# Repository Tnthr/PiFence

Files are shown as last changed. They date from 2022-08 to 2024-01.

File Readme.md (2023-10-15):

# About PiFence

An arduino script and a shell script for use as a fence agent on a custom built power supply for a five node raspberry pi cluster.

The shell script is a fence agent designed to be used with pacemaker in a HA environment. 
The Arduino program is for an Arduino with ethernet shield connected to five seperate relays that operate five USB power supplies. This setup allows the Arduino to function as a STONITH device for a five node Raspberry Pi cluster.

The whole project is pretty rough but it works well enough for "production" use. Plenty of room for improvement though.
Recently added the first revision of a custom PCB. All of the files are from KiCAD. I do not recommend using this PCB design as is because it is extremely simple and only uses various breakout boards. The next version will be a real PCB that includes all of the discrete components. 

The project is designed to fit into a Raspberry Pi cluster case to be self-contained. Link to the case used is below.
https://www.printables.com/en/model/182055-raspberry-pi-4-cluster-case

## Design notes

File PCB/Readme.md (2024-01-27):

# About PiFence PCB

The fence device is custom-made hardware that is run by the firmware in this repository. This PCB folder is the hardware.

The core of the hardware is an Arduino that controls five relays powering five USB ports. These ports provide power to each of five Raspberry Pi devices and the Arduino provides fencing capability. The Arduino has an ethernet port interface to provide external control.

The board has a power port for 18V input to supply the arduino and the five powered USB ports. 

Future plans include adding a USB C power input, two four-pin fan outputs, a 12V power output for the router, and integrating the ethernet port as well as converting the power outputs to USB C.

# Theory

The USB-C PD spec can deliver 20 volts and 5 amps which will provide up to 100 watts. This is plenty to power all of the board components. An alternate option is 15 volts at 3 amps. This will be just enough to power everything so long as there is not a high load on anything. Futher testing is probably required to ensure at least the initial bootup of all servers can be handled at the lower power level before providing support for it.

At the 20 volt input level power cannot be applied directly to the Arduino so a power step down will be required. A 12V step down will allow power to be applied to the arduino and to the router. A 5V step down with enough current output will be needed for the RPi power outputs and the fans.

Control of the fans should be provided by the Arduino. A temperature sensor will be added to the computer area of the case to provide input for controlling the speed of the fans.

# Component list

| Item | Model | Quantity |
| --- | --- | --- |
| MCU | Arduino Nano Every | 1 |
| 12V Step down | | 1 |
| 5V Step down  | | ? |
| Ethernet jack | | 1 |
| Relay | PR13-5V-450-1C | 5 |
| Temp sensor | | 1 |
| USB C Port | | 6 |

# Power requirements for all of the components

| Item | Qty | Volt | Draw | Total  |
| --- | --- | ---- | ---- | --- |
| RPi4 | 5 | 5V | 1.3A | 32.5W  |
| Fan | 2 | 5V | 0.2A | 2W |
| Router  | 1 | 12V  | 1A | 12W |
| Arduino | 1 | 5V | 25mA | 0.125W |

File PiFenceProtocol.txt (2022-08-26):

# PiFence protocol standard
# Version 0.1
# 15 August 2022

# This will describe the protocol used by my homemade power supply and fence device
# for a Raspberry Pi cluster. The protocol uses UDP packets to communicate between 
# the cluster and the arduino + ethernet shield that controls the power supply.

3 bytes for the request. All information is ASCII encoded

First byte
R = request

Second byte
S = Status
K = Kill
R = Reboot
P = Power on

Third byte
[1-9] = port number

Responses are just quick words mostly "Success". The script currently ignores responses anyway.

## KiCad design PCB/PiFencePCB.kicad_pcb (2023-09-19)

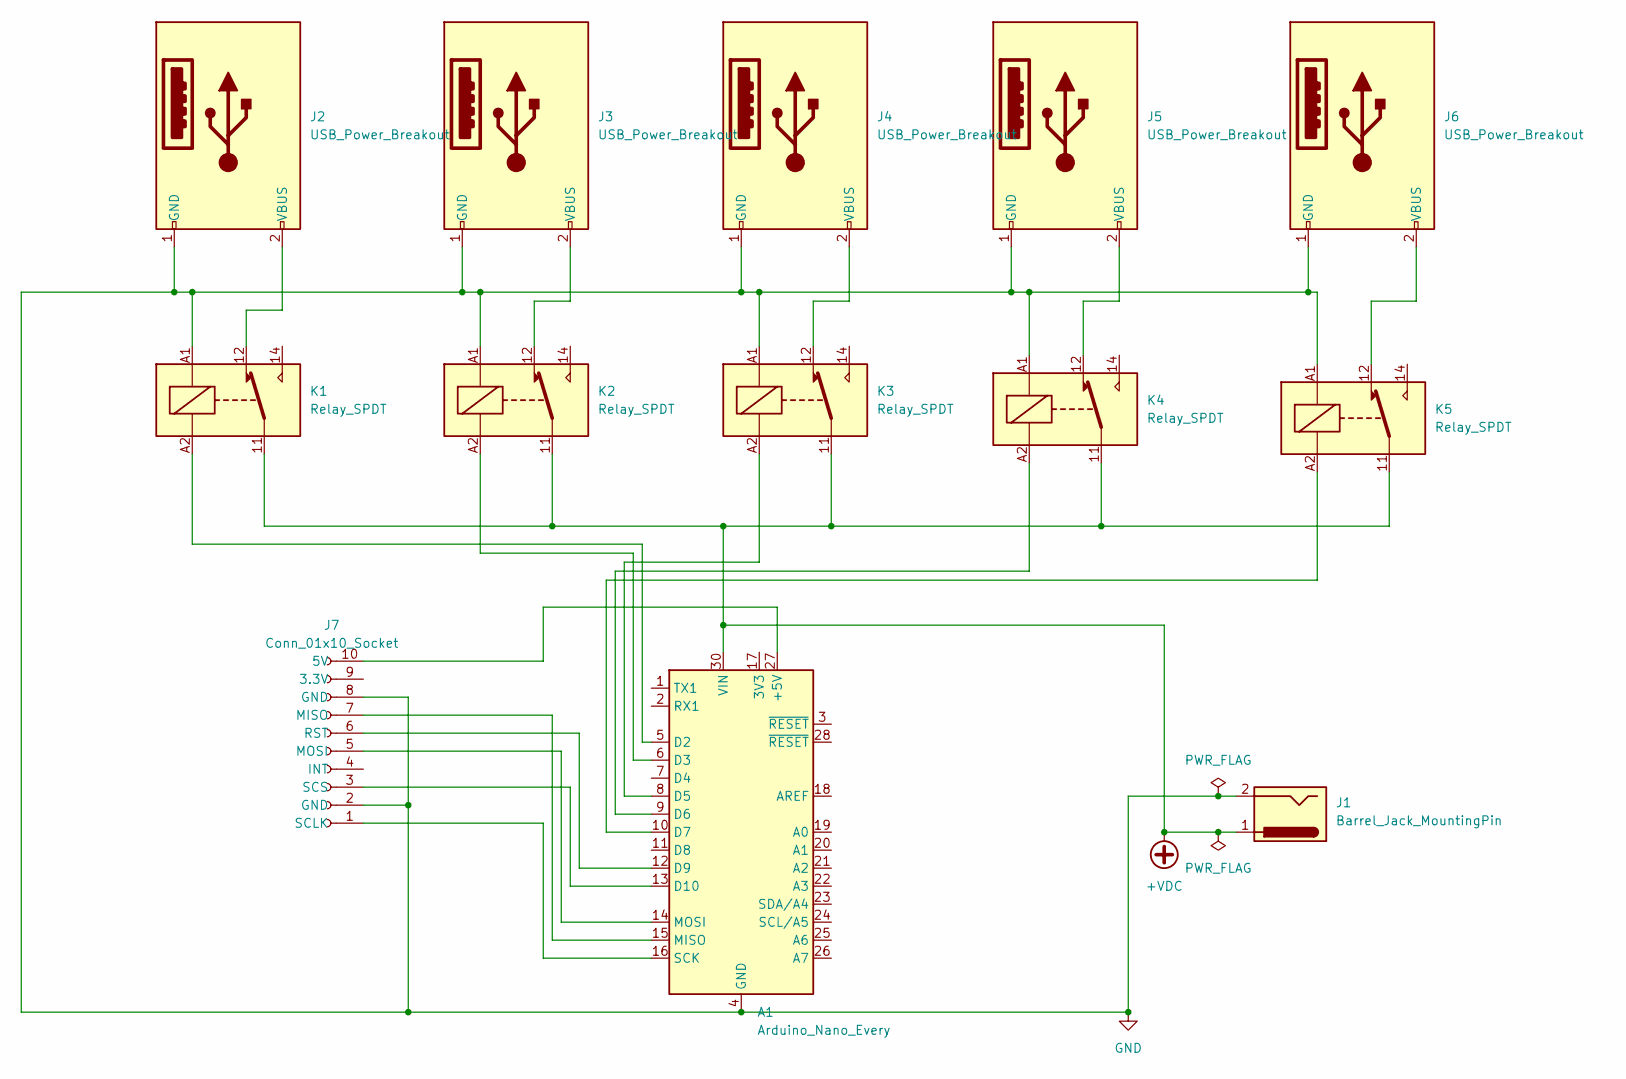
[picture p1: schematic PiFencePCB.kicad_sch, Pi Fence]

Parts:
A1: Arduino_Nano_Every; Arduino_Nano
J1: Barrel_Jack_MountingPin; BarrelJack_CUI_PJ-036AH-SMT_Horizontal
J2, J3, J4, J5, J6: USB_Power_Breakout; USB_Breakout_Board
J7: Conn_01x10_Socket; PinSocket_2x05_P2.54mm_Vertical
K1, K2, K3, K4, K5: Relay_SPDT; Relay_SPDT_Finder_36.11

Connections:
+VDC: A1.30 (VIN), J1.1, K1.11, K2.11, K3.11, K4.11, K5.11
GND: A1.4 (GND), A1.29 (GND), J1.2, J2.1 (GND), J3.1 (GND), J4.1 (GND), J5.1 (GND), J6.1 (GND), J7.2 (GND), J7.8 (GND), K1.A1, K2.A1, K3.A1, K4.A1, K5.A1
unnamed: A1.27 (+5V), J7.10 (5V)
unnamed: A1.5 (D2), K1.A2
unnamed: A1.6 (D3), K2.A2
unnamed: A1.8 (D5), K3.A2
unnamed: A1.9 (D6), K4.A2
unnamed: A1.10 (D7), K5.A2
unnamed: A1.12 (D9), J7.6 (RST)
unnamed: A1.13 (D10), J7.3 (SCS)
unnamed: A1.15 (MISO), J7.7 (MISO)
unnamed: A1.14 (MOSI), J7.5 (MOSI)
unnamed: A1.16 (SCK), J7.1 (SCLK)
unnamed: J2.2 (VBUS), K1.12
unnamed: J3.2 (VBUS), K2.12
unnamed: J4.2 (VBUS), K3.12
unnamed: J5.2 (VBUS), K4.12
unnamed: J6.2 (VBUS), K5.12

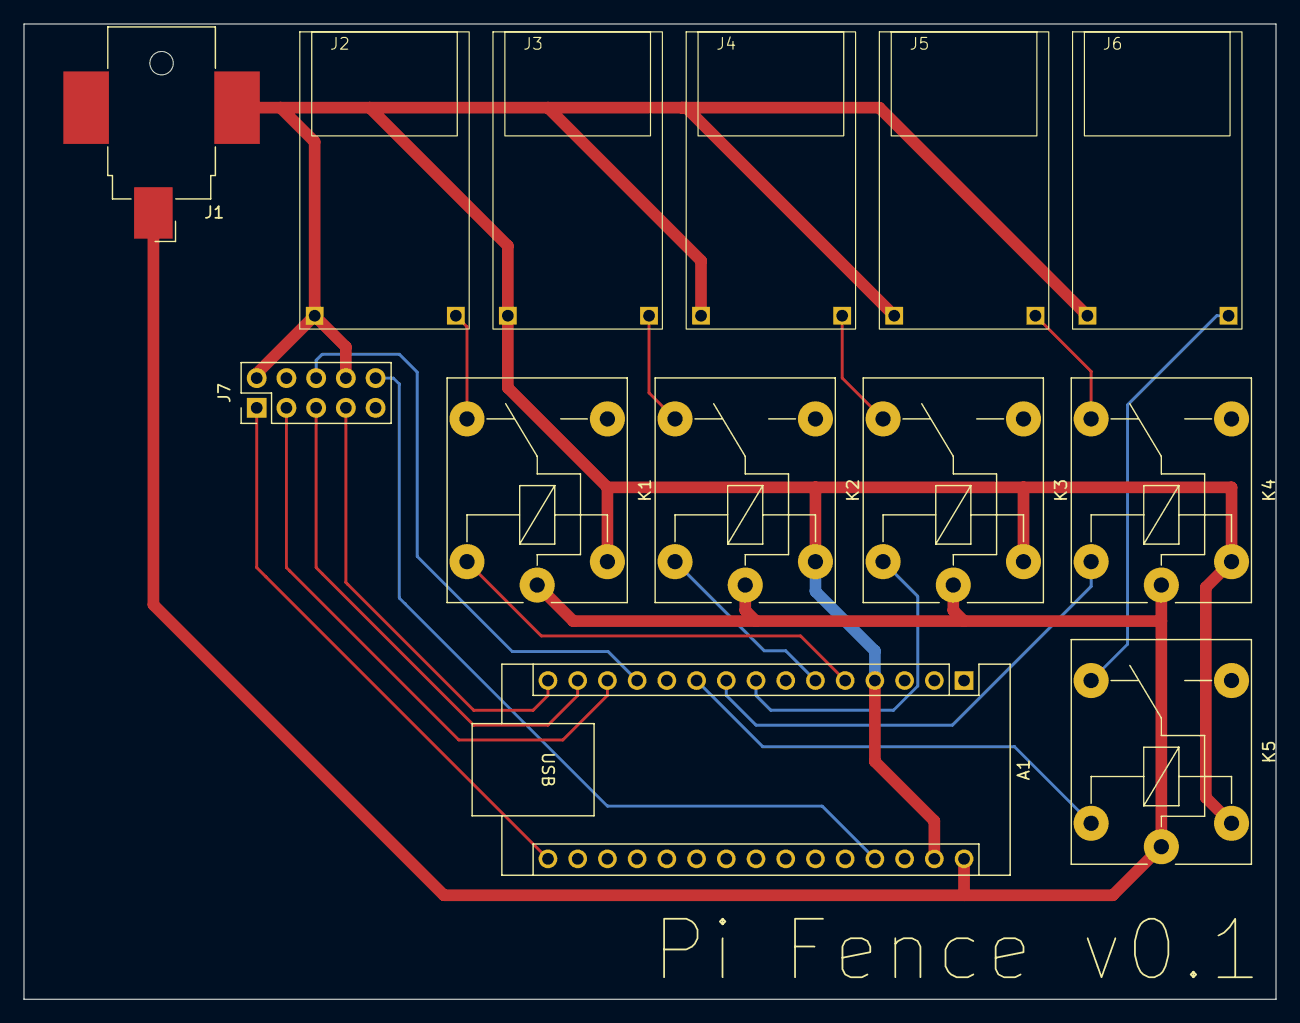
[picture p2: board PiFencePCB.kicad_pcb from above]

Board: 2 copper layers, 107.0 x 83.3 mm, 13 parts (0 on the bottom side), 18 nets.

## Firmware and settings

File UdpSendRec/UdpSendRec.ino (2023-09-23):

/*
 Pi Fence arduino sketch
 Used to manage a power supply for a Raspberry Pi Cluster
 Based on the Example shown below.
 Written by Brian Jenkins
 15 August 2022


 Udp NTP Client
 Get the time from a Network Time Protocol (NTP) time server
 Demonstrates use of UDP sendPacket and ReceivePacket
 For more on NTP time servers and the messages needed to communicate with them,
 see http://en.wikipedia.org/wiki/Network_Time_Protocol

 created 4 Sep 2010
 by Michael Margolis
 modified 9 Apr 2012
 by Tom Igoe
 modified 02 Sept 2015
 by Arturo Guadalupi

 This code is in the public domain.

 */

#include <Ethernet.h>
#include <EthernetUdp.h>
#include <SPI.h>

// #define DEBUG 1

#define POWEROFF HIGH
#define POWERON LOW

// The MAC address for the controller
byte mac[] = {0xDE, 0xAD, 0xBE, 0xB0, 0x0B, 0x1E}; // For production with IP 10.0.1.77
// byte mac[] = {0xDE, 0xAD, 0x02, 0xB0, 0x0B, 0x1E}; // For testing with IP 10.0.1.55

unsigned int localPort = 11089; // local port to listen for UDP packets
const int PACKET_SIZE = 48;     // Data packet is no more than 48 bytes
char packetBuffer[PACKET_SIZE]; // buffer to hold incoming and outgoing packets
char ReplyBuffer[PACKET_SIZE] = "ACK\n"; // a string to send back
int portPinStatus[6][3] = {
    {0, 0, 0}, // lazy filler
    {1, 2, 1}, // node 1 pin 2
    {2, 3, 1}, // node 2 pin 3
    // Skipped pin 4 because of some interference
    {3, 5, 1}, // node 3 pin 5
    {4, 6, 1}, // node 4 pin 6
    {5, 7, 1}  // node 5 pin 7
};
const int PIN = 1;
const int STATUS = 2;

// A UDP instance to let us send and receive packets over UDP
EthernetUDP Udp;

void setup() {
  // Set the relay pins to output and power on.
  for (int x = 1; x <= 5; x++) {
    pinMode(portPinStatus[x][1], OUTPUT);
    digitalWrite(portPinStatus[x][1], POWERON);
  }

#ifdef DEBUG
  // Open serial communications and wait for port to open:
  Serial.begin(9600);
  while (!Serial) {
    ; // wait for serial port to connect. Needed for native USB port only
  }

  Serial.println("Serial opened.");
#endif

  // start Ethernet and UDP
  if (Ethernet.begin(mac) == 0) {
#ifdef DEBUG
    Serial.println("Failed to configure Ethernet using DHCP");
    //  Check for Ethernet hardware present
    if (Ethernet.hardwareStatus() == EthernetNoHardware) {
      Serial.println(
          "Ethernet not found.  Sorry, can't run without hardware. :(");
    } else if (Ethernet.linkStatus() == LinkOFF) {
      Serial.println("Ethernet cable is not connected.");
    }
#endif
    // no point in carrying on, so do nothing forevermore:
    while (true) {
      delay(1);
    }
  } else {
#ifdef DEBUG
    if (Ethernet.linkStatus() == Unknown) {
      Serial.println("Link status unknown.");
    } else if (Ethernet.linkStatus() == LinkON) {
      Serial.println("Link status: On");
    } else if (Ethernet.linkStatus() == LinkOFF) {
      Serial.println("Link status: Off");
    }
#endif
  }
  Udp.begin(localPort);
#ifdef DEBUG
  Serial.println(Ethernet.localIP());
  Serial.println("Waiting for data...");
#endif
}

void loop() {
  // if there's data available, read a packet
  if (Udp.parsePacket()) {
    // read the packet into packetBuffer
    Udp.read(packetBuffer, PACKET_SIZE);

    // second char is the node number (1-5) which is converted to int
    int portNum = (packetBuffer[2] - '0');

    // zeroth character always R; first is what the request is
    if (packetBuffer[0] == 'R') { // This means its a request
      switch (packetBuffer[1]) {
      case 'S': // Status
#ifdef DEBUG
        Serial.println("Got an R and S");
#endif
        if (portPinStatus[portNum][STATUS] == 1) {
          strcpy(ReplyBuffer, "ON\n");
#ifdef DEBUG
          Serial.print("Port is ON: ");
          Serial.println(portNum);
#endif
        } else {
          strcpy(ReplyBuffer, "OFF\n");
#ifdef DEBUG
          Serial.print("Port is OFF: ");
          Serial.println(portNum);
#endif
        }
        break;
      case 'K': // Kill
#ifdef DEBUG
        Serial.println("Got an R and K");
#endif
        digitalWrite(portPinStatus[portNum][PIN], POWEROFF);
        portPinStatus[portNum][STATUS] = 0;
        strcpy(ReplyBuffer, "Success\n");
        break;
      case 'R': // Reboot
#ifdef DEBUG
        Serial.println("Got an R and R");
#endif
        digitalWrite(portPinStatus[portNum][PIN], POWEROFF);
        portPinStatus[portNum][STATUS] = 0;
        delay(2000); // 2 seconds delay should be enough
        digitalWrite(portPinStatus[portNum][PIN], POWERON);
        portPinStatus[portNum][STATUS] = 1;
        strcpy(ReplyBuffer, "Success\n");
        break;
      case 'P': // Power On
#ifdef DEBUG
        Serial.println("Got an R and P");
#endif
        digitalWrite(portPinStatus[portNum][PIN], POWERON);
        portPinStatus[portNum][STATUS] = 1;
        strcpy(ReplyBuffer, "Success\n");
        break;
      }
    }

    // send a reply, to the IP address and port that sent us the packet
    Udp.beginPacket(Udp.remoteIP(), Udp.remotePort());
    Udp.write(ReplyBuffer);
    Udp.endPacket();
  }

  Ethernet.maintain();
}

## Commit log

2022-08-15 complete change for template of arduino sketch
2023-01-04 added config for VSCode Arduino
2023-09-19 Added PCB files
    [PiFencePCB-B_Cu.gbr, PiFencePCB-B_Mask.gbr, PiFencePCB-B_Paste.gbr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]
2023-09-23 dont commit with kicad still open
2023-10-15 Update Readme.md
    added link to printable case.
2024-01-27 Added a PCB readme. Some small changes to the schematic
    [PiFencePCB.kicad_sch]
